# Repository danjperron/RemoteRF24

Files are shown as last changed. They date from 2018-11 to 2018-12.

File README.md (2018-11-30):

# RemoteRF24
Exemple de remote control utilisant des arduinos  avec des nrf24L01.

N'est pas encore completement fonctionnel.

il reste a ajouter la logique du tamis au remote.
A modifier l'action des leds au remote.
Vérifier en émulant le hall effect du tambour et le bras du cone.
Enlever les printf et seulement les ajouter en mode debug.

Ultérieurement nous pourrions utiliser le acknoledge pour envoyer les donnés ce qui augmenterais de beaucoup la vitesse de transfer.

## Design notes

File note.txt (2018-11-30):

Tous on des arduino uno r3 comme microcontroleur

Telecomande (emeteur)
5 entré configuré pour bouton poussoir

Message a envoyer=
bouton 1 =envoie un signal a toute les machines pour stop tout
bouton 2 =envoie signal au cone pour stop le feeder(active un relais sur le uno du cone)
bouton 3 =envoie signal au cone pour start le feeder (desactive un relais sur sur le uno du cone)
bouton 4 =envoie signal au primaire pour stop le feeder(active un relais sur le uno du primaire)
bouton 5 =envoie signal au primaire pour start le feeder(desactive un relais sur le uno du primaire)

--------------------------------------------

Cone Crusher(emeteur ,recepteur)

2 relais en mode sortie
1 push buttom en mode entré

relay 1 ( actice,desactive feeder)
relay 2 (actice,desactive une lumiere avertissement blanche)

message a envoyer=
signal 1 =(stop tout)
signal 2 =(stop feeder primaire)
signal 3 =(strat feeder primaire)

reception du signal:
signal bouton 1 ou signal 1 du tamis = active le relais (stop le feeder)
signal bouton 3 desactive le relais (start le feeder)

le uno recois un signal dun push buttom instaler sur un bras mecanique du cone pour conaitre letat du feeder (actif ou non actif)
quand non actif active relay 2
quand actif desactive relay 2

le uno passe en mode emission 

si le pushbuttom non actif durant plus de 10 sec : envois signal 1 du cone au tamis et au primaire
ausito que non actif : envoi signal 2 au primaire si redevien actif avant les 10sec attend 5 sec et envois signal 3

-------------------------------------------------

Tamis (emeteur ,recepteur)

2 relais en mode sortie
1 hall efect sensor en mode entré

signal a envoyer a tout les machine 

signal 1 tamis (stop tout)

recois des signaux de la telecomande et du cone
envoi des signaux au cone et au primaire

recepetion:
bouton 1 de la telecomande ou signal 1 du cone=
stop le tamis (active un relais durant 1 sec, le coupe et active un autre relais durant 1 sec et la coupe aussi)

lecture du rpm par le hallsensor si moin de 1 rpm

passe en mode emission
envoie : signal 1 du tamis (pour stop tamis, feeder cone et feeder primaire)

----------------------------------------------------------

Primaire Crusher (recepteur)
1 relais en mode sortie

Relais active = stop feeder

relais a activer quand recois le signal bouton 1 de la telecomande ou signal 1 du tamis ou signal 1 du cone ou signal 2 du cone
desactiver quand recois le signal 3 du cone

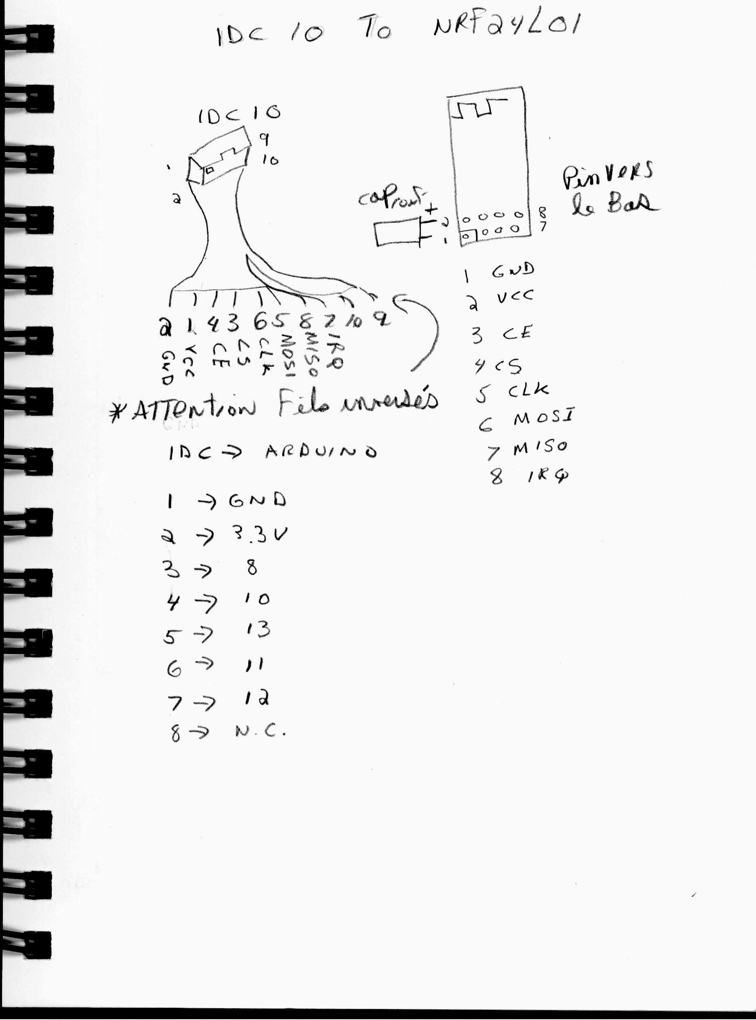
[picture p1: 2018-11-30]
IDC10_nrf24L01.jpeg

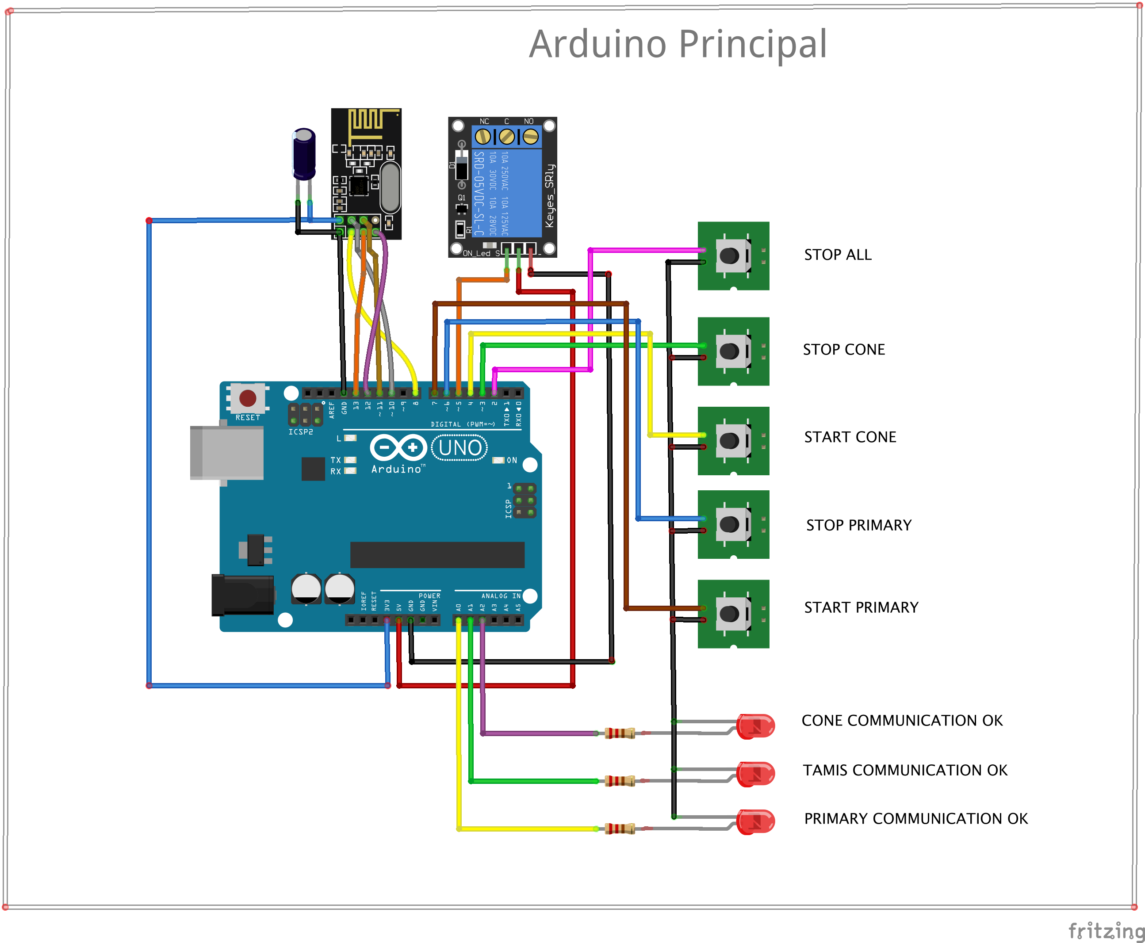
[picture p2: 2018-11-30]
Fritzing/emetteur_nrf24l01.png

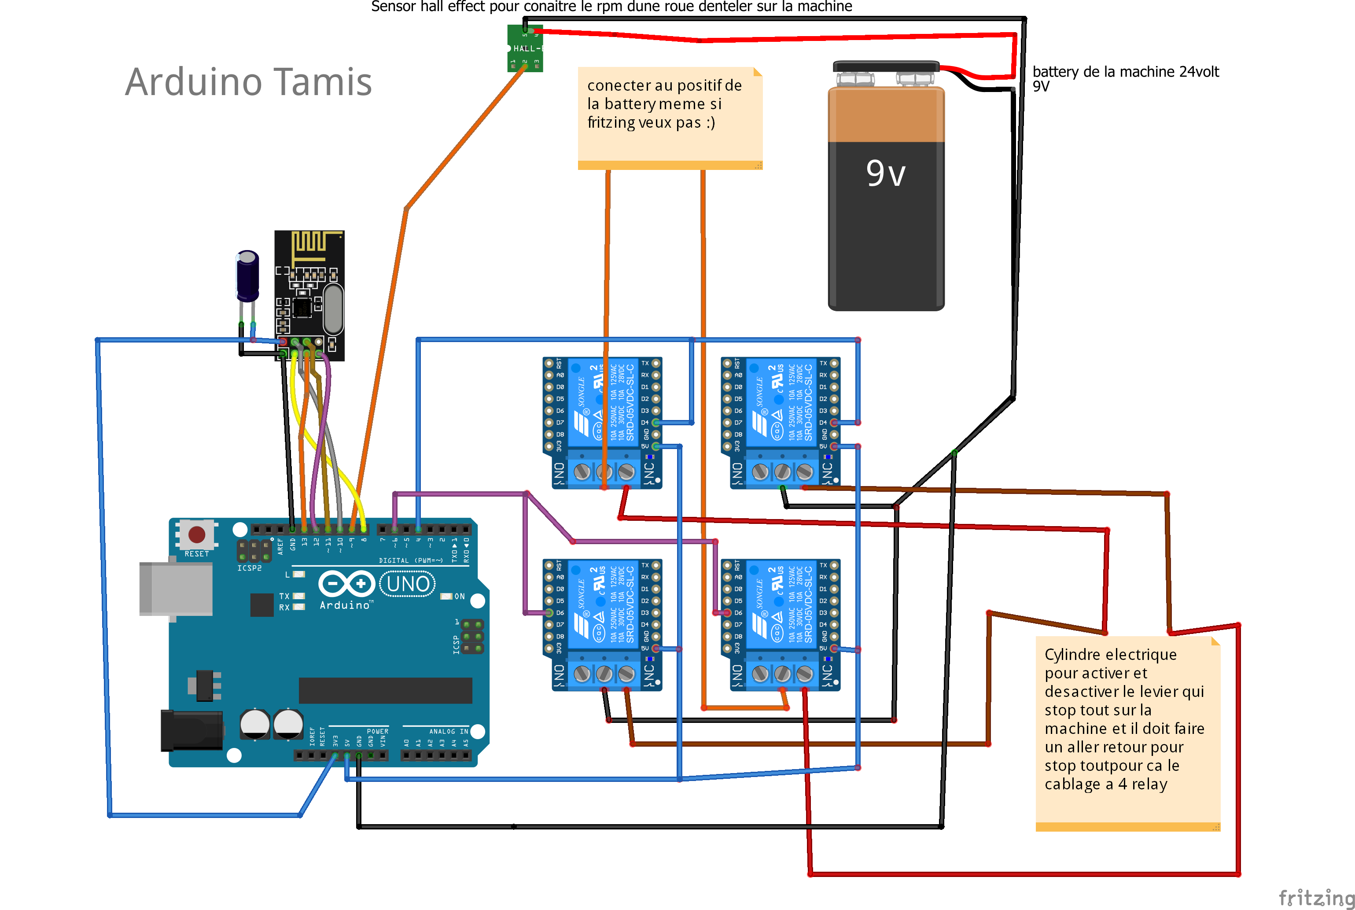
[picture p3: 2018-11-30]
Fritzing/adruino-pour-le-tamis_bb.png

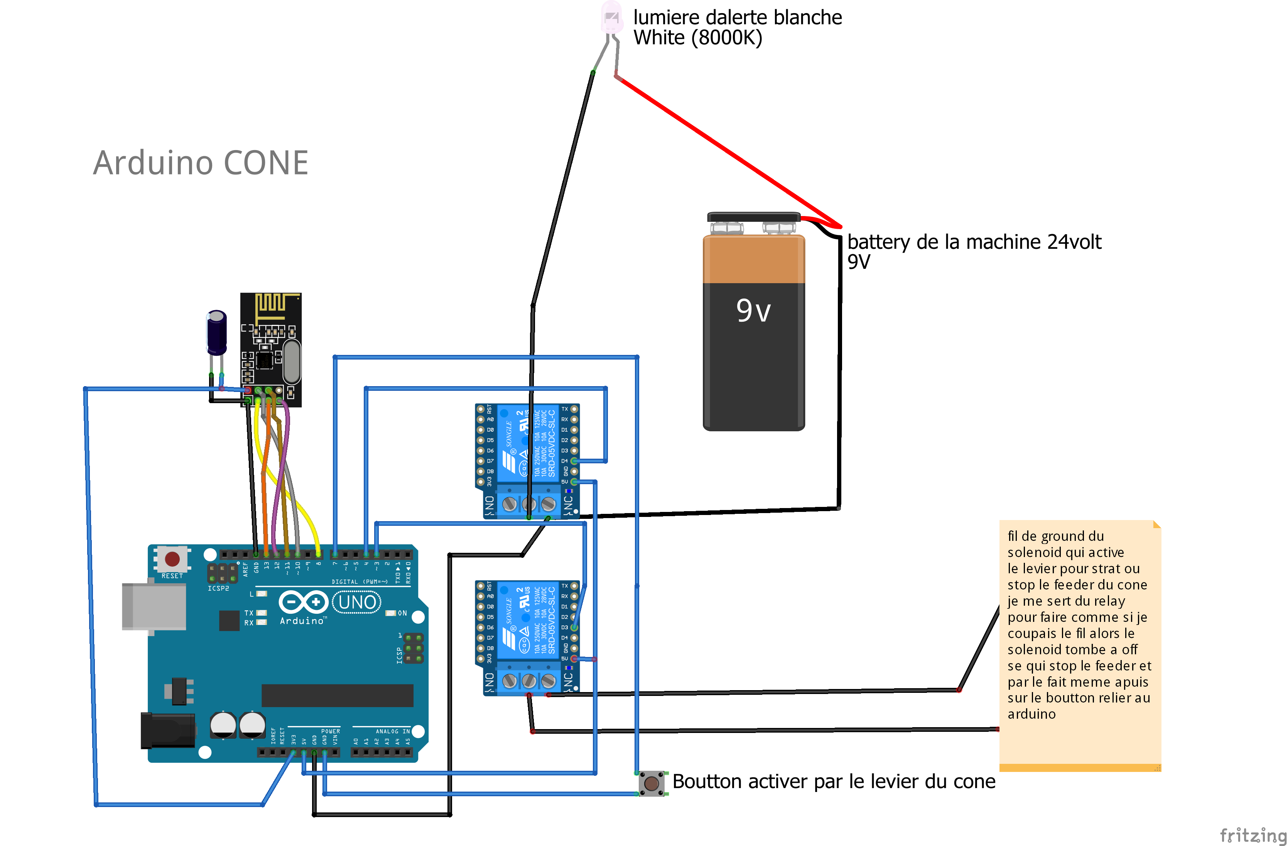
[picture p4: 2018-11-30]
Fritzing/adruino-pour-le-cone_bb.png

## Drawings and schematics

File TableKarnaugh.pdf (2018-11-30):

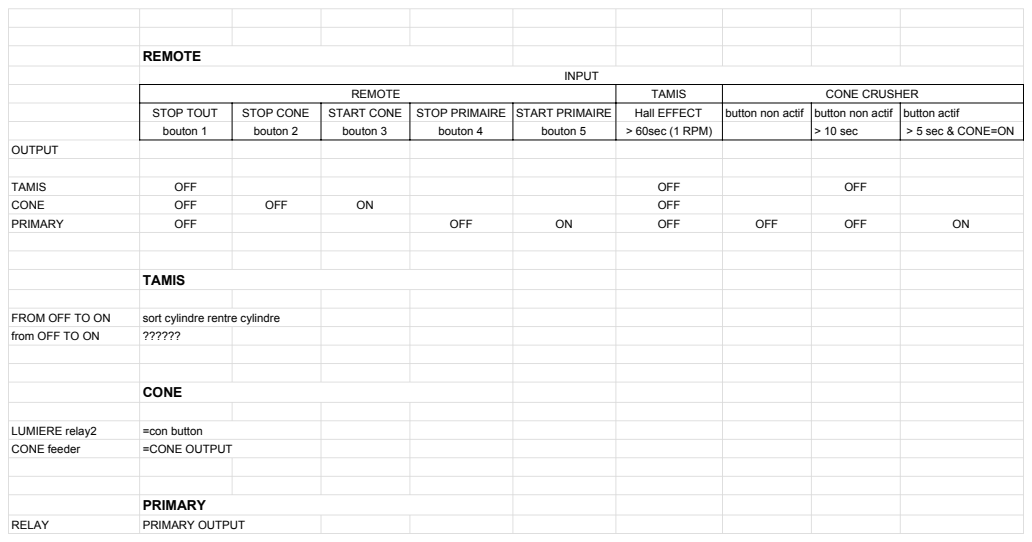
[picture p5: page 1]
REMOTE; INPUT; OUTPUT; TAMIS; OFF; CONE; PRIMARY; FROM OFF TO ON; sort cylindre rentre cylindre; from OFF TO ON; LUMIERE relay2; =con button; CONE feeder; =CONE OUTPUT; RELAY; PRIMARY OUTPUT

REMOTE | TAMIS | CONE CRUSHER

STOP TOUT bouton 1 | STOP CONE bouton 2 | START CONE bouton 3 | STOP PRIMAIRE bouton 4 | START PRIMAIRE bouton 5 | Hall EFFECT > 60sec (1 RPM) | button non actif | button non actif > 10 sec | button actif > 5 sec & CONE=ON

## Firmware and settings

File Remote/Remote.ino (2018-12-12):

#include <SPI.h>
#include "RF24.h"
#include "printf.h"

const uint8_t RF24_CANAL=83;

// pour tester
// permet d'enlever une unité spécifique pour vérifier le fonctionnement

#define ENABLE_TAMIS
#define ENABLE_CONE
//#undef ENABLE_TAMIS
//#undef ENABLE_CONE

#define ENABLE_PRIMARY
#undef ENABLE_PRIMARY


#define LED_ON HIGH
#define LED_OFF LOW


/*
 *  remote control utilisant un nrf24L01
 *  PUSH BUTTON DEFINITION
 *  
 */

#define SERIAL_DEBUG
//#undef SERIAL_DEBUG

 
const uint8_t BOUTON_STOP_ALL=2;
const uint8_t BOUTON_STOP_CONE=3;
const uint8_t BOUTON_START_CONE=4;
const uint8_t BOUTON_STOP_PRIMARY=6;
const uint8_t BOUTON_START_PRIMARY=7;




/* DEBOUNCE  INFO avec status des bouttons dans une seule variable
 *  un byte est utilisé avec les bits recevant l'info des bouttons
 *  currentBoutons => valeurs des bouttons actuelles
 *  LastBoutons    => valeurs passées  des bouttons 
 *  debounceBoutons =>  temps capturé de  millis() depuis un changement de boutton
 *
 *   si pas de changement sur les bouttons depuis  plus de DEBOUNCE_MIN then currentB = LastB
 */


// bit weight de chaque boutton


const uint8_t BIT_STOP_ALL=1;
const uint8_t BIT_STOP_CONE=2;
const uint8_t BIT_START_CONE=4;
const uint8_t BIT_STOP_PRIMARY=8;
const uint8_t BIT_START_PRIMARY=16;

uint8_t rpm=0;  // valeur en rpm que le tamis retourne
                // si 0 arrête tout


 // 50 ms debounce pour les bouttons semblent bon
const int DEBOUNCE_MIN=50;


 /*  
 *  Indicateur LED pour indiquer si les RF24 sont visibles.
 */

const uint8_t LED_PRIMARY=A0;
const uint8_t LED_TAMIS=A1;
const uint8_t LED_CONE=A2;

   

 // variable pour le debounce

unsigned long tempMilli;     // variable temporaire pour lecture millis()
unsigned char tempBoutons;    // variable temporaire pour lecture boutons
unsigned char currentBoutons= BIT_STOP_ALL;  //par défaux bouton 1 pressé (tout à OFF).
unsigned char lastBoutons=currentBoutons;  
unsigned long debounceBoutons = millis();          // debounce current time en milli sec;
unsigned long currentLapse= debounceBoutons;    // timer pour envoyer le data  toute les 0.1 sec.

// variable pour le time out des LEDS
// indiquant une bonne communication des unités

unsigned long tempsValide_PRIMARY = 0;
unsigned long tempsValide_CONE = 0;
unsigned long tempsValide_TAMIS = 0;

bool Valide_PRIMARY = false;
bool Valide_CONE = false;
bool Valide_TAMIS = false;

bool BoutonConeInactif10sec = false;
const unsigned long RF24_TIMEOUT=10000;

/* variable principale pour les sorties 
 *  l'information envoyer au remote est seulement un byte encoder par le bit définie pour chaque sortie
 *  donc nous avons le tamis, le cone et le primary
 */

uint8_t PRIMARY_ON=1;
uint8_t CONE_ON=2;
uint8_t TAMIS_ON=4;  // seulement status par tamis
uint8_t FORCE_TAMIS_OFF=8;


unsigned int UnitsOutput= 0; // all off on boot

/* variable retourner par les rf24 satellites
 *  
 *  Le tamis retourne le RPM 
 *  Le cone  retourne le status du boutton avec le delay depuis le dernier changement
 *  
 */



// set radio pin 8 CE , pin 10 CS

RF24 radio(8, 10); 


 
const uint64_t RF24_REMOTE  =0xF0F0F0F0E1LL;
const uint64_t RF24_TAMIS   =0xF0F0F0F0D1LL;
const uint64_t RF24_CONE    =0xF0F0F0F0D2LL;
const uint64_t RF24_PRIMARY =0xF0F0F0F0D3LL;

const uint8_t ID_REMOTE=0xE1;
const uint8_t ID_TAMIS=0xD1;
const uint8_t ID_CONE=0xD2;
const uint8_t ID_PRIMARY=0xD3;


/* LireBoutons
 *  retourne valeur de chaque boutton dans une valeur binaire
 */

unsigned char lireBoutons(void)
{
    unsigned char bValue=0;
    if (digitalRead(BOUTON_STOP_ALL) == LOW)
       bValue = BIT_STOP_ALL;
    if (digitalRead(BOUTON_STOP_CONE) == LOW)
       bValue |= BIT_STOP_CONE;
    if (digitalRead(BOUTON_START_CONE) == LOW)
       bValue |= BIT_START_CONE;
    if (digitalRead(BOUTON_STOP_PRIMARY) == LOW)
       bValue |= BIT_STOP_PRIMARY;
    if (digitalRead(BOUTON_START_PRIMARY) == LOW)
       bValue |= BIT_START_PRIMARY;
    return bValue;
}


// decode les boutons
void decodeAction(void)
{          
#ifdef SERIAL_DEBUG
  printf("Decode Action  avant = %d  rpm=%d",UnitsOutput,rpm);
#endif

   if(currentBoutons & BIT_START_CONE)
   {
     if(rpm>0)
     {
      UnitsOutput |= CONE_ON;
#ifdef SERIAL_DEBUG
      printf("=== START CONE ===\n");
#endif      
   }
        else
        {
#ifdef SERIAL_DEBUG
      printf("=== START CONE IMPOSSIBLE RPM=0 ===\n");
#endif
          
        }

   
   }

   if(currentBoutons & BIT_START_PRIMARY)
   {
      if(rpm>0)
        {
         UnitsOutput |= PRIMARY_ON;
#ifdef SERIAL_DEBUG
      printf("=== START PRIMARY ===\n");
#endif
        }
        else
        {
#ifdef SERIAL_DEBUG
      printf("=== START PRIMARY IMPOSSIBLE RPM=0 ===\n");
#endif
          
        }
   }

   // maintenant les stop;

   if(currentBoutons & BIT_STOP_PRIMARY)
   {
      UnitsOutput &= ~PRIMARY_ON;
#ifdef SERIAL_DEBUG
      printf("=== STOP_PRIMARY ===\n");
#endif      
   }

   if(currentBoutons & BIT_STOP_CONE)
   {
      UnitsOutput &= ~CONE_ON;
#ifdef SERIAL_DEBUG
      printf("=== STOP CONE ===\n");
#endif 
   }
   
   if(currentBoutons & BIT_STOP_ALL)
   {
      UnitsOutput = FORCE_TAMIS_OFF; 
#ifdef SERIAL_DEBUG
      printf("=== STOP ALL ===\n");
#endif      
   }

#ifdef SERIAL_DEBUG
printf("apres = %d\n",UnitsOutput);
#endif      
}


unsigned char datapacket[3];



unsigned char SendInfo( uint64_t RF24_TX,unsigned char ID, unsigned char value)
{
  bool ok;
  uint8_t pipe_number;
  
#ifdef SERIAL_DEBUG
   printf("radio => %2lx%lx ",(uint32_t)(RF24_TX>>32),(uint32_t) (RF24_TX));
   printf("value = %d  ",value);
#endif   
   radio.stopListening(); 
   radio.openWritingPipe(RF24_TX);
   datapacket[0]=ID_REMOTE;
   datapacket[1]=UnitsOutput;
   ok=radio.write(datapacket,2);
 
  radio.startListening();
  // maintenant attentons pour un réponse
  unsigned long waitdelay = millis();
  while(1)
    {
      if(radio.available(&pipe_number))
        {
           if(pipe_number==1)
             {
               if(radio.read(datapacket,3))
                 {
                   if(datapacket[0] != ID)
                   {
                     #ifdef SERIAL_DEBUG
                       printf("wrong packet\n\r");
                     #endif
                   }
                  else
                  {
                    // ok nous avons eu une réponse  
                    #ifdef SERIAL_DEBUG
                    printf("return %d %d \n\r",datapacket[1],datapacket[2]);
                    #endif
                    break;
                  }
                 }

             }
            else
             {
              radio.read(datapacket,3);
             }          
        }
      
      if((millis() - waitdelay) > 50)
       {
        #ifdef SERIAL_DEBUG
         printf("return time out\n");
        #endif 
         radio.stopListening();
         return(0); // ok time out retourne 0
       }
    }
      radio.stopListening();
   return ok;
}



/*
 * Envoie à chaque unité l'information des sorties
 * 
 */
void syncInformation(void)
{
 delay(20);
#ifdef ENABLE_TAMIS
  #ifdef SERIAL_DEBUG
   printf("TAMIS :");
  #endif 
  // Envoi info au TAMIS  retourne   RPM
    if(SendInfo(RF24_TAMIS,ID_TAMIS,UnitsOutput))
     {
         tempsValide_TAMIS=millis();
         Valide_TAMIS = true;
         // TAMIS retourne la valeur en RPM boutton 
         // datapacket[0] ID_TAMIS
         // datapacket[1] RPM
         // datapacket[2] DRUM STATUS  0=DRUM OFF  1=DRUM ON
         rpm  = datapacket[1];
         // le status du TAMIS est généré par le tamis
         //  donc ajustons le status du Tamis
         if(datapacket[2])
           UnitsOutput |= TAMIS_ON;
          else
           UnitsOutput &= ~TAMIS_ON;
         
         if( rpm == 0)
          {
            // est-ce que le Tambour fonctionne
            // ok all off
            if(datapacket[2])
                UnitsOutput = FORCE_TAMIS_OFF;
            else
                UnitsOutput= 0;    
          }
     }
     else
     {
      if((millis() - tempsValide_TAMIS) >  RF24_TIMEOUT)
        {
              // ok time out sur la communication allons faire un stop complet
               UnitsOutput = 0;
               Valide_TAMIS = false;
        }
     }
#endif



#ifdef ENABLE_PRIMARY
  #ifdef SERIAL_DEBUG  
   printf("PRIMARY :");
  #endif
  // Envoi info au PRIMARY CRUSHER
   if( SendInfo(RF24_PRIMARY,ID_PRIMARY,UnitsOutput))
    {
      // reset time out
      tempsValide_PRIMARY=millis();
      Valide_PRIMARY=true;
    }
    else
    { // ok je n'ai pas réussi a communiquer avec le RF24_PRIMARY

      if((millis() - tempsValide_PRIMARY) >  RF24_TIMEOUT)
        {
              // ok time out sur la communication allons faire un stop complet
               UnitsOutput = FORCE_TAMIS_OFF;
               Valide_PRIMARY=false;
        }
    }
#endif
 

#ifdef ENABLE_CONE 
  #ifdef SERIAL_DEBUG
   printf("CONE :");
  #endif 
  // Envoi info au CONE_CRUSHER
    if(SendInfo(RF24_CONE,ID_CONE,UnitsOutput))
     {
         tempsValide_CONE=millis();
         Valide_CONE = true;
         // cone crusher retourne la valeur du boutton et le delay depuis son changement
         // datapacket[0] c'est ID_CONE
         // datapacket[1] c'est l'etat du bouton
         // datapacket[2] c'est le temps en secondes
         if(UnitsOutput&CONE_ON)
         {
         if(datapacket[1]>0)  
           {

               // bouton non actif  == non pesé??
               // donc primary OFF
               UnitsOutput &= ~PRIMARY_ON;
               // si ca fait plus de 10 secondes
               if(datapacket[2] > 10)
                {
                 UnitsOutput &= ~TAMIS_ON;
                 UnitsOutput |= FORCE_TAMIS_OFF;
                 BoutonConeInactif10sec = true;  // specifie que le bouton est inactif depuis 10 secondes
                }
                else
                  BoutonConeInactif10sec = false;
           }
           else
           {
              // bouton ACTIF  pesé??
              // était inactif depuis 10 sec 
              if(BoutonConeInactif10sec)
               {
                if(datapacket[2] > 5)
                    UnitsOutput |= PRIMARY_ON;
               }
               else
                   UnitsOutput |= PRIMARY_ON;
               
           }
         }
          else
          {
             // cone crusher off donc PRIMARY OFF
               UnitsOutput &=  PRIMARY_ON;
          }
         
           // si RPM == 0 stop tout anyway
           if(rpm == 0)
            UnitsOutput = FORCE_TAMIS_OFF;
     }
     else
     {
      if((millis() - tempsValide_CONE) >  RF24_TIMEOUT)
        {
              // ok time out sur la communication allons faire un stop complet
               UnitsOutput = FORCE_TAMIS_OFF;
               Valide_CONE = false;
         }
     }
#endif


}
     
 
void setup()
{
  pinMode(BOUTON_STOP_ALL, INPUT);
  pinMode(BOUTON_STOP_CONE, INPUT);
  pinMode(BOUTON_START_CONE, INPUT);
  pinMode(BOUTON_STOP_PRIMARY, INPUT);
  pinMode(BOUTON_START_PRIMARY, INPUT);
  digitalWrite(BOUTON_STOP_ALL, HIGH);
  digitalWrite(BOUTON_STOP_CONE, HIGH);
  digitalWrite(BOUTON_START_CONE, HIGH);
  digitalWrite(BOUTON_STOP_PRIMARY, HIGH);
  digitalWrite(BOUTON_START_PRIMARY, HIGH);
    
  pinMode(LED_PRIMARY, OUTPUT);
  pinMode(LED_TAMIS, OUTPUT);
  pinMode(LED_CONE, OUTPUT);
  
  digitalWrite(LED_PRIMARY, LOW);
  digitalWrite(LED_TAMIS, LOW);
  digitalWrite(LED_CONE, LOW);


  
  printf_begin();
  Serial.begin(115200);

  Serial.println("NRF24L01 Transmitter");

  radio.begin();
  radio.setChannel(RF24_CANAL);  // par 76 par defaux 
  radio.setDataRate(RF24_1MBPS);
  radio.setRetries(15,15);
  radio.setPayloadSize(8);
  radio.setPALevel(RF24_PA_HIGH);
  radio.openReadingPipe(1,RF24_REMOTE);
  radio.startListening();
  #ifdef SERIAL_DEBUG
  radio.printDetails();
  #endif
}


void loop() {

unsigned long cTimer = millis();

// maintenant vérifions les boutons
unsigned char _tBoutons = lireBoutons();

// est-ce la même valeur
 if(_tBoutons != lastBoutons)
    {
      // ok les boutons ne sont pas stable attendons
      debounceBoutons = cTimer;
      lastBoutons = _tBoutons;
    }
    else
    {
      // est-ce que les bouttons on changé depuis le debounce
      if(_tBoutons != currentBoutons)
      {
        // est-ce que le débounce est fait
        if((debounceBoutons - cTimer) > DEBOUNCE_MIN)
           {
              // ok debounce est fait donc 
              currentBoutons = _tBoutons;
              currentLapse = cTimer;
              // Decode Boutons Action
              decodeAction();
              syncInformation();
              currentLapse = cTimer;
           }
      }
    }





// Vérifier si cela fait plus de 1 seconde
// que nous avons pas envoyer . Si oui envoyons l'info

if( (cTimer - currentLapse) > 1000)
  {

    #ifdef SERIAL_DEBUG
      printf("Units Output = %d  rpm=%d\n",UnitsOutput,rpm);
    #endif 
     // 1 seconde écoulée  envoyons.
    syncInformation();
    currentLapse = cTimer;
  }

// status des leds
// allumer ou éteind donne l'état des stations
// flash rapide veut dire pas de communication avec la station


// led PRIMAIRE
if(Valide_PRIMARY)
   {
      digitalWrite(LED_PRIMARY, UnitsOutput & PRIMARY_ON ? LED_ON : LED_OFF);
         
   }
else
   {
       // pas de communication
       digitalWrite(LED_PRIMARY, (millis() & 256) ? HIGH : LOW);        
   }

// led CONE
if(Valide_CONE)
   {
      digitalWrite(LED_CONE, UnitsOutput & CONE_ON ? LED_ON : LED_OFF); 
         
   }
else
   {
       // pas de communication
       digitalWrite(LED_CONE, (millis() & 256) ? HIGH : LOW);        
   }

// led TAMIS
if(Valide_TAMIS)
   {
      digitalWrite(LED_TAMIS, UnitsOutput & TAMIS_ON ? LED_ON : LED_OFF); 
         
   }
else
   {
       // pas de communication
       digitalWrite(LED_TAMIS, (millis() & 256) ? HIGH : LOW);        
   }

}

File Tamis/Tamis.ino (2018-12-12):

#include <SPI.h>
#include "nRF24L01.h"
#include "RF24.h"
#include "printf.h"


// definition de l'activation des relays
#define RELAY_NC  HIGH
#define RELAY_NO  LOW 

const uint8_t RF24_CANAL=83;

#define SERIAL_DEBUG
//#undef SERIAL_DEBUG

// verification si le rf24 recoit encore
unsigned long tempsValide = 0;
bool Valide = false;
const unsigned long RF24_TIMEOUT=10000;
const unsigned long HALL_EFFECT_DEBOUNCE=100;  //100ms debounce

const uint64_t RF24_REMOTE  =0xF0F0F0F0E1LL;
const uint64_t RF24_TAMIS   =0xF0F0F0F0D1LL;
const uint64_t RF24_CONE    =0xF0F0F0F0D2LL;
const uint64_t RF24_PRIMARY =0xF0F0F0F0D3LL;



const uint8_t ID_REMOTE=0xE1;
const uint8_t ID_TAMIS=0xD1;
const uint8_t ID_CONE=0xD2;
const uint8_t ID_PRIMARY=0xD3;

const unsigned int nb_Aimant = 6;
int Relay1 = 4;
int Relay2 = 3;
int DataMsg[1];
int sensorState = 0;
unsigned int rpm=0;
unsigned long pulseEcart;  // le temps entre deux impulsions
unsigned long timeold;
volatile int rpmcount=0;
unsigned long rpmTime;


bool DrumRun=false;
bool DrumEnStop=false;
unsigned long DrumDelay;

RF24 radio(8, 10);

// buffer pour transmission receptio
unsigned char Rcvdatapacket[2];
unsigned char Txmdatapacket[3];




/* variable principale pour les sorties 
 *  l'information envoyer au remote est seulement un byte encoder par le bit définie pour chaque sortie
 *  donc nous avons le tamis, le cone et le primary
 */

uint8_t PRIMARY_ON=1;
uint8_t CONE_ON=2;
uint8_t TAMIS_ON=4;
uint8_t FORCE_TAMIS_OFF=8;
// output mirroir
unsigned int UnitsOutput= 0; // all off on boot



int cycle=0;
unsigned long cycle_delay;

void rpm_fun()
{
  rpmcount=1;

}

void setup()
{
  printf_begin();
// hall effect transistor doit etre sur la pin 2 pour interrupt 0
  pinMode(2,INPUT);
  digitalWrite(2,HIGH);
  attachInterrupt(0, rpm_fun, FALLING);
  pinMode(Relay1, OUTPUT);
  pinMode(Relay2, OUTPUT);
  Serial.begin(115200);
  radio.begin();
  radio.setChannel(RF24_CANAL);  // par 76 par defaux 
  radio.setRetries(15,15);
   radio.setPALevel(RF24_PA_HIGH);
  radio.setPayloadSize(8);
  radio.stopListening();
  radio.openWritingPipe(0);
  radio.openReadingPipe(1,RF24_TAMIS);
  radio.startListening();
  #ifdef SERIAL_DEBUG
    radio.printDetails();
  #endif
  tempsValide=millis();
  timeold=millis()-1;
  rpmcount=0;
  rpmTime=0;
}




void CylindreCycle(void)
{
  switch(cycle)
  {
    case 0 : break;  // ne fait rien
    case 1 : //sort cylindre
            digitalWrite(Relay1, RELAY_NO);
            cycle_delay = millis();
            cycle = 2;
            break;
    case 2  : // attends 1 seconde
            if((millis() - cycle_delay) > 1000)
              {
                // ok coupe signal
                cycle_delay=millis();
                digitalWrite(Relay1, RELAY_NC);
                cycle = 3;                
              }
              break;
   case 3:   // attends 10 ms
            if((millis() - cycle_delay) > 10)
              {
                // ok rentre cylindre
                cycle_delay=millis();
                digitalWrite(Relay2, RELAY_NO);
                cycle = 4;                
              }
              break;
    case 4  : // attends 1 seconde
            if((millis() - cycle_delay) > 1000)
              {
                // ok coupe signal
                cycle_delay=millis();
                digitalWrite(Relay2, RELAY_NC);
                cycle = 5;                
              }
              break;
   case 5:   // attends 10 ms
            if((millis() - cycle_delay) > 10)
              {
                cycle = 0; // c'est fini                
                DrumEnStop=true;
                DrumDelay=millis();
              }
              break;
  default:    cycle = 0;
              
  }
   
}


void loop() {
uint8_t pipe_number;



  CylindreCycle();
  if (rpmcount >= 1) {

     pulseEcart = (millis() - timeold);
     timeold = millis();
    // est-ce que l'écart entre les deux impulsion est trop longue
    if(pulseEcart < (60000 / nb_Aimant))  // pour empêcher une compte d'amorcer le ON
    if(pulseEcart > HALL_EFFECT_DEBOUNCE)
    {
      // temps écoulé avec le dernier interrup ok donc c'est valide
       rpm = (60000 * rpmcount) / (nb_Aimant * (millis() - timeold)); //6 a changer si le nombre daimant est different
#ifdef SERIAL_DEBUG
       printf("irq => rpm %d\n\r",rpm);
#endif
    }
    rpmcount = 0;
  }
  else
  {
// ok derniere impulsion remonte a quand
// si pas d'impulsion pour moins de 1 rpm set rpm=0
   rpmTime = millis() - timeold;

   if(rpmTime > (60000 / nb_Aimant))
     rpm = 0;

   // ajuste rpm time en seconde
   // pour raporter le temps en seconde depuis le dernier aimant
   if(rpmTime > 255000)
      rpmTime= 255000;  // ne peut pas depasser 255 secondes
    rpmTime/=1000;
   
  }


 // verifions si le tambour est en train de s'arrêter
  if(DrumEnStop)
    {
       // un petit delay d'une seconde pour assurer que mécaniquement
       // le drum est en arrêt
       if((millis()-DrumDelay) > 1000)
        {
           DrumEnStop=false;
           DrumRun=false;
           rpm=0;
        }
    }


  // si le tambour est en arret et que j'ai un RPM donc je roule
  
  if(rpm > 0)
    DrumRun= true;

  
  if(radio.available(&pipe_number))
  {
  if(pipe_number==1)
  {
    // ok nous avons une connection
    // lisons l'info 
    if(radio.read(Rcvdatapacket,2))
    {
    if(Rcvdatapacket[0]==ID_REMOTE)
    {  
    // envoyons bac1k;
    UnitsOutput = Rcvdatapacket[1];
    if(UnitsOutput & FORCE_TAMIS_OFF)
     if(DrumRun)  // est-ce que le drum roule
     {
       if(!DrumEnStop) // est-ce que le délais pour arrêt est 
         if(cycle==0) // est-ce que le cylindre est en standby
           cycle=1;  // ok fait l cycle
       DrumRun=false;
     }

    // ok encore besoin de faire la logique avec le rpm 

    Txmdatapacket[0]=ID_TAMIS;
    Txmdatapacket[1]= rpm;
    Txmdatapacket[2]= DrumRun;
    radio.stopListening();
    delay(5);
    radio.openWritingPipe(RF24_REMOTE);
    radio.write(Txmdatapacket,3);
    delay(1);
    radio.openWritingPipe(0);
    radio.startListening();
    #ifdef SERIAL_DEBUG
      printf("recu UnitsOutput= %d\n",Rcvdatapacket[1]);
      printf("transmet %d %d\n",Txmdatapacket[1],Txmdatapacket[2]);
    #endif
    tempsValide=millis();
    }
    }
  }
  else
  {
    radio.read(Rcvdatapacket,1);
  }
  }
  else
  {
    // pas de connection
    // time out
    if((millis()-tempsValide) > RF24_TIMEOUT)
    {
       // ok time out tout mettre a zero
       UnitsOutput =0;
   }
  
  }

  }

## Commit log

2018-11-30 premiere version
    [adruino-pour-le-cone.fzz, adruino-pour-le-primaire.fzz, adruino-pour-le-tamis.fzz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]
2018-12-02 ajoute control effet de Hall
2018-12-12 fixe led, relais et cone push button
    [Cone.ino, Primary.ino, Remote.ino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]
